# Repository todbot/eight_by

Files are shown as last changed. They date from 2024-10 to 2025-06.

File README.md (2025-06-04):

# eight_by

An 8-knob + 8 buttons + eight RGB LEDs board,<br/>
all controllable with only 8 pins

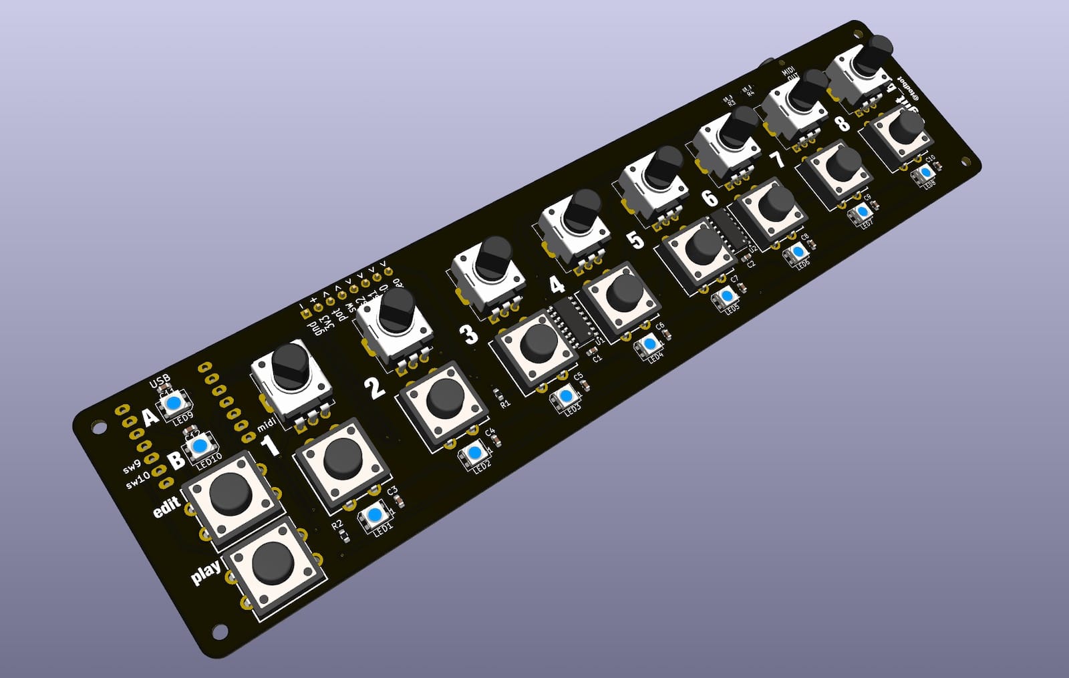
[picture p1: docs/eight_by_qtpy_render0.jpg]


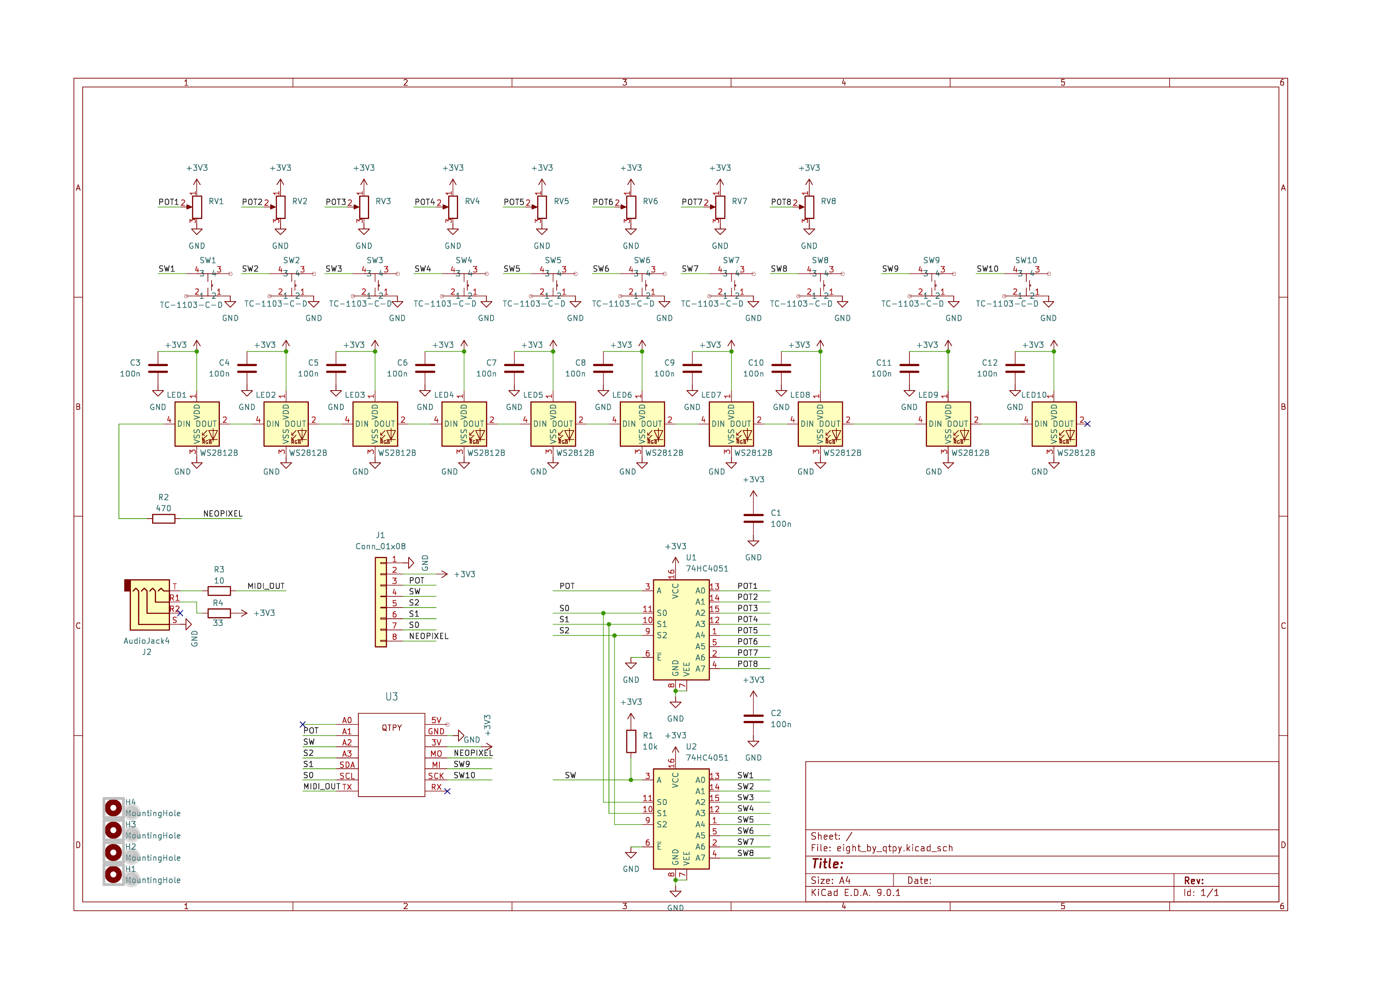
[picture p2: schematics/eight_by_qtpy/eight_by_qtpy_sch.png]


Pot options:

- 9mm Song Hui trimmer pots B10K - [synthcube](https://synthcube.com/cart/parts/potentiometers-and-trimpots/song-huei-9mm-panel-trim-pot-short)
- Just about any other 9mm pot

Buttons are: 
- 12mm tact (LCSC C561260)

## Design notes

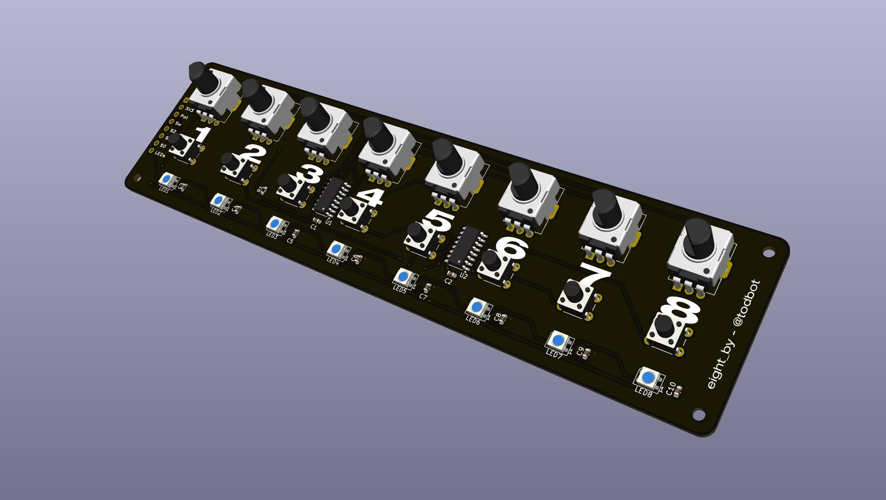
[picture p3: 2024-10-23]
docs/eight_by_render0.jpg

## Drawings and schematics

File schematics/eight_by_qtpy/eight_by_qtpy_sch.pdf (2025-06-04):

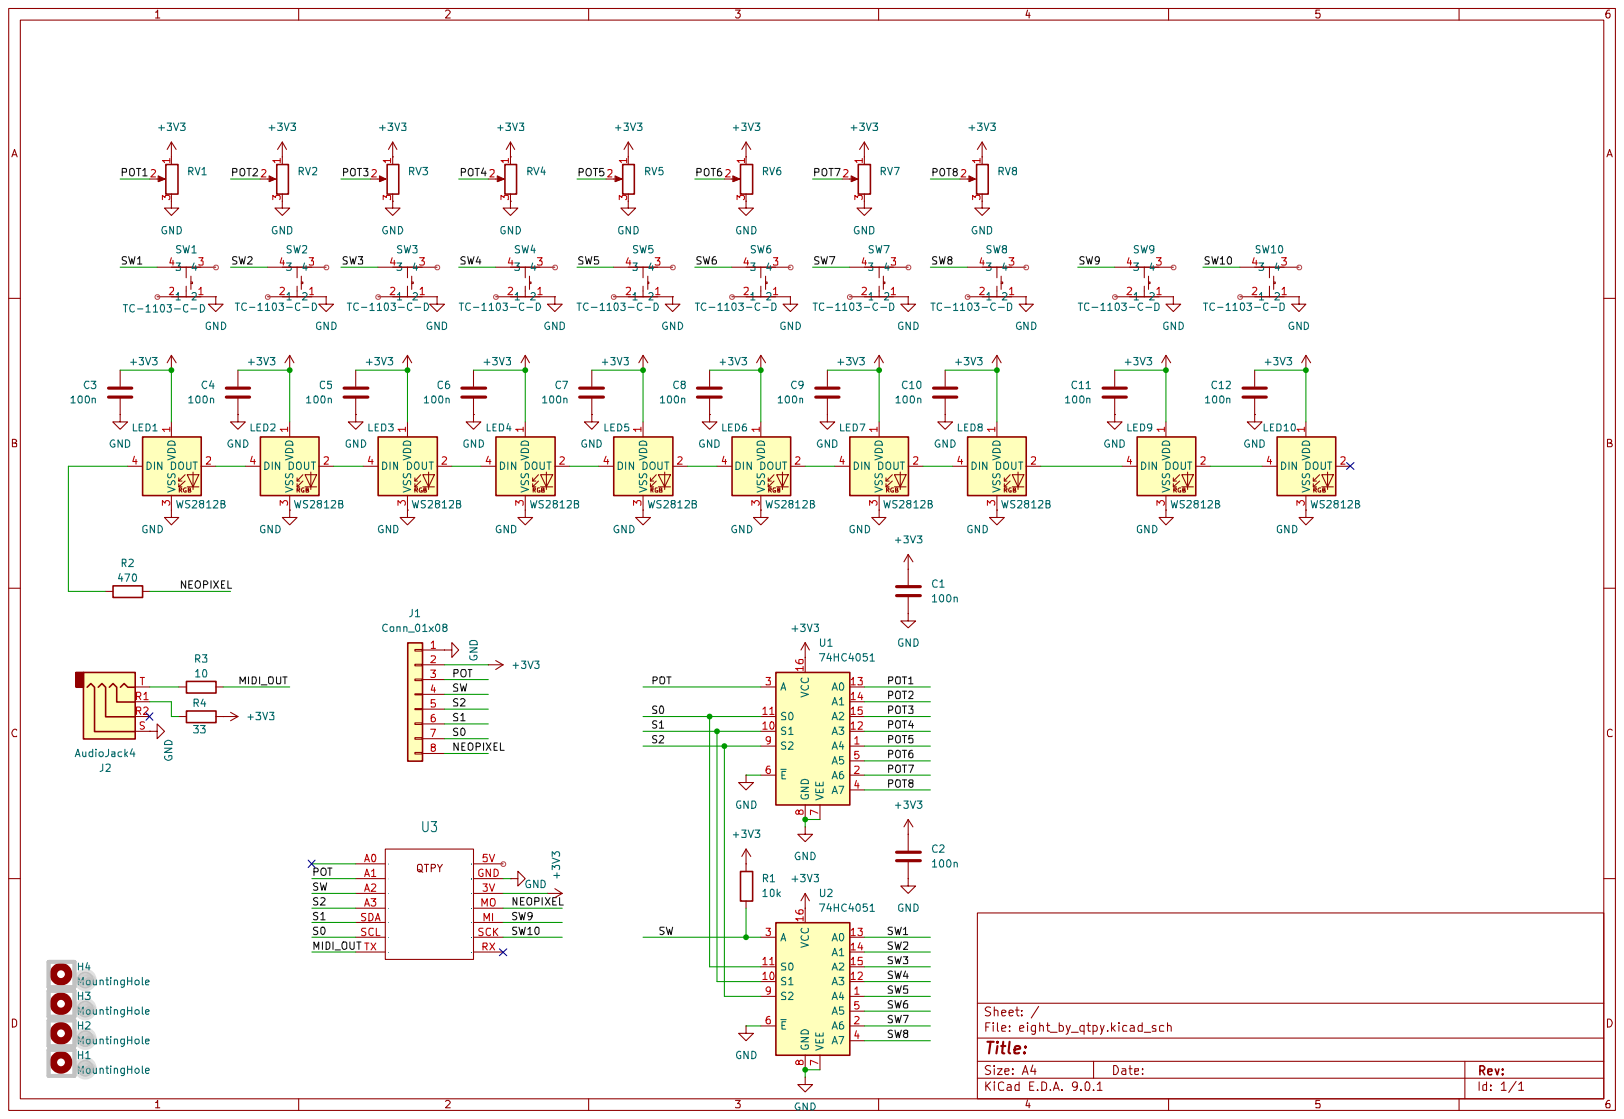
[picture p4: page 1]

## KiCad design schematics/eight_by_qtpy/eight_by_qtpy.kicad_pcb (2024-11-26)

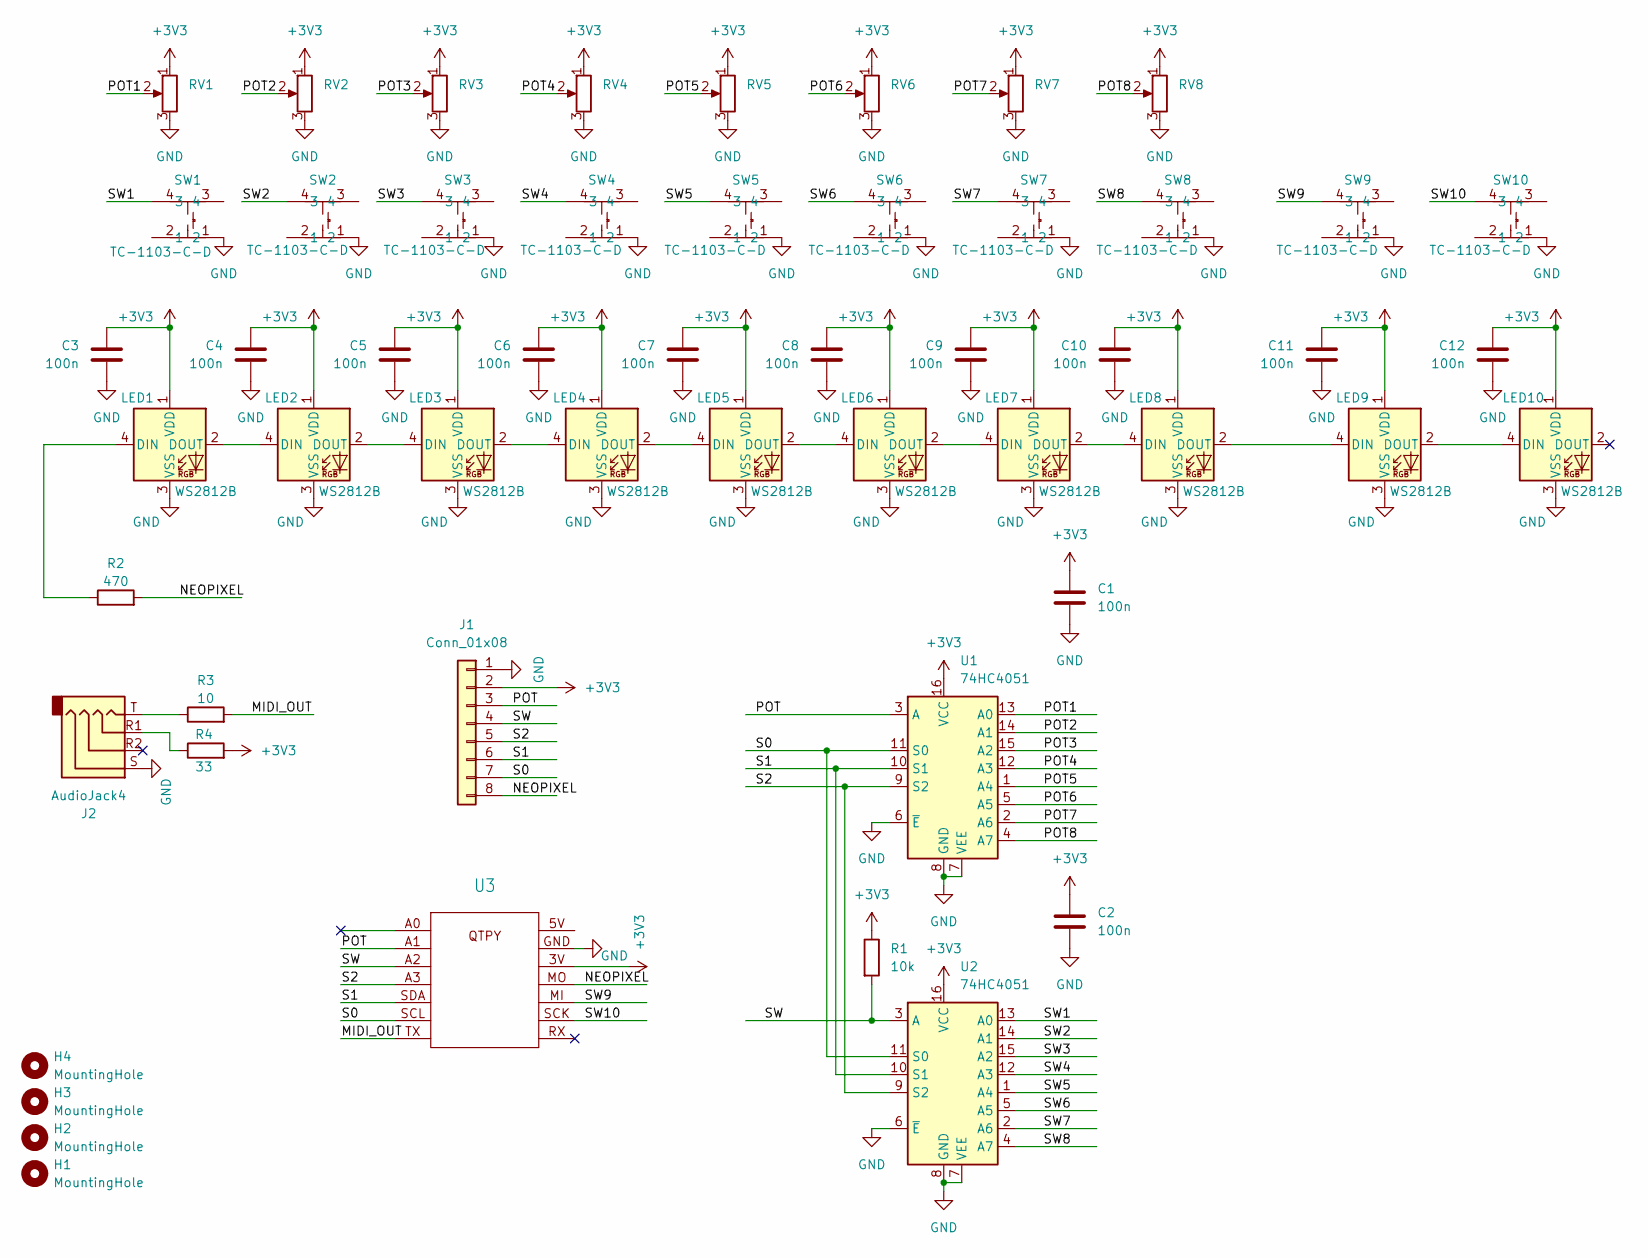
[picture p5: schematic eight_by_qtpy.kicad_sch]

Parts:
C1, C2, C3, C4, C5, C6, C7, C8, C9, C10, C11, C12: 100n; C_0603_1608Metric
H1, H2, H3, H4: MountingHole; MountingHole_2.5mm
J1: Conn_01x08; PinHeader_1x08_P2.54mm_Vertical
J2: AudioJack4; Jack_3.5mm_PJ320D_Horizontal
LED1, LED2, LED3, LED4, LED5, LED6, LED7, LED8, LED9, LED10: WS2812B; LED_WS2812B-Mini_PLCC4_3.5x3.5mm
R1: 10k; R_0603_1608Metric
R2: 470; R_0603_1608Metric
R3: 10; R_0603_1608Metric
R4: 33; R_0603_1608Metric
RV1, RV2, RV3, RV4, RV5, RV6, RV7, RV8: R_Potentiometer; Potentiometer_Alps_RK09K_Single_Vertical
SW1, SW2, SW3, SW4, SW5, SW6, SW7, SW8, SW9, SW10: TC-1103-C-D; SW-TH_4P-L12.0-W12.0-P5.00-LS12.5; LCSC Part C561260
U1, U2: 74HC4051; SOIC-16_3.9x9.9mm_P1.27mm
U3: QTPY_TH_HEADERSOCKET

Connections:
+3V3: C1.1, C2.1, C3.1, C4.1, C5.1, C6.1, C7.1, C8.1, C9.1, C10.1, C11.1, C12.1, J1.2, LED1.1 (VDD), LED2.1 (VDD), LED3.1 (VDD), LED4.1 (VDD), LED5.1 (VDD), LED6.1 (VDD), LED7.1 (VDD), LED8.1 (VDD), LED9.1 (VDD), LED10.1 (VDD), R1.1, R4.2, RV1.1, RV2.1, RV3.1, RV4.1, RV5.1, RV6.1, RV7.1, RV8.1, U1.16 (VCC), U2.16 (VCC), U3.3V
/MIDI_OUT: R3.2, U3.TX
/NEOPIXEL: J1.8, R2.2, U3.MO
/POT: J1.3, U1.3 (A), U3.A1 (9)
/POT1: RV1.2, U1.13 (A0)
/POT2: RV2.2, U1.14 (A1)
/POT3: RV3.2, U1.15 (A2)
/POT4: RV4.2, U1.12 (A3)
/POT5: RV5.2, U1.1 (A4)
/POT6: RV6.2, U1.5 (A5)
/POT7: RV7.2, U1.2 (A6)
/POT8: RV8.2, U1.4 (A7)
/S0: J1.7, U1.11 (S0), U2.11 (S0), U3.SCL
/S1: J1.6, U1.10 (S1), U2.10 (S1), U3.SDA
/S2: J1.5, U1.9 (S2), U2.9 (S2), U3.A3
/SW: J1.4, R1.2, U2.3 (A), U3.A2
/SW1: SW1.4, U2.13 (A0)
/SW2: SW2.4, U2.14 (A1)
/SW3: SW3.4, U2.15 (A2)
/SW4: SW4.4, U2.12 (A3)
/SW5: SW5.4, U2.1 (A4)
/SW6: SW6.4, U2.5 (A5)
/SW7: SW7.4, U2.2 (A6)
/SW8: SW8.4, U2.4 (A7)
/SW9: SW9.4, U3.MI
/SW10: SW10.4, U3.SCK
GND: C1.2, C2.2, C3.2, C4.2, C5.2, C6.2, C7.2, C8.2, C9.2, C10.2, C11.2, C12.2, J1.1, J2.S, LED1.3 (VSS), LED2.3 (VSS), LED3.3 (VSS), LED4.3 (VSS), LED5.3 (VSS), LED6.3 (VSS), LED7.3 (VSS), LED8.3 (VSS), LED9.3 (VSS), LED10.3 (VSS), RV1.3, RV2.3, RV3.3, RV4.3, RV5.3, RV6.3, RV7.3, RV8.3, SW1.1, SW2.1, SW3.1, SW4.1, SW5.1, SW6.1, SW7.1, SW8.1, SW9.1, SW10.1, U1.6 (~E), U1.7 (VEE), U1.8 (GND), U2.6 (~E), U2.7 (VEE), U2.8 (GND), U3.GND (14)
unnamed: J2.R1, R4.1
unnamed: J2.T, R3.1
unnamed: LED1.4 (DIN), R2.1
unnamed: LED1.2 (DOUT), LED2.4 (DIN)
unnamed: LED2.2 (DOUT), LED3.4 (DIN)
unnamed: LED3.2 (DOUT), LED4.4 (DIN)
unnamed: LED4.2 (DOUT), LED5.4 (DIN)
unnamed: LED5.2 (DOUT), LED6.4 (DIN)
unnamed: LED6.2 (DOUT), LED7.4 (DIN)
unnamed: LED7.2 (DOUT), LED8.4 (DIN)
unnamed: LED8.2 (DOUT), LED9.4 (DIN)
unnamed: LED9.2 (DOUT), LED10.4 (DIN)

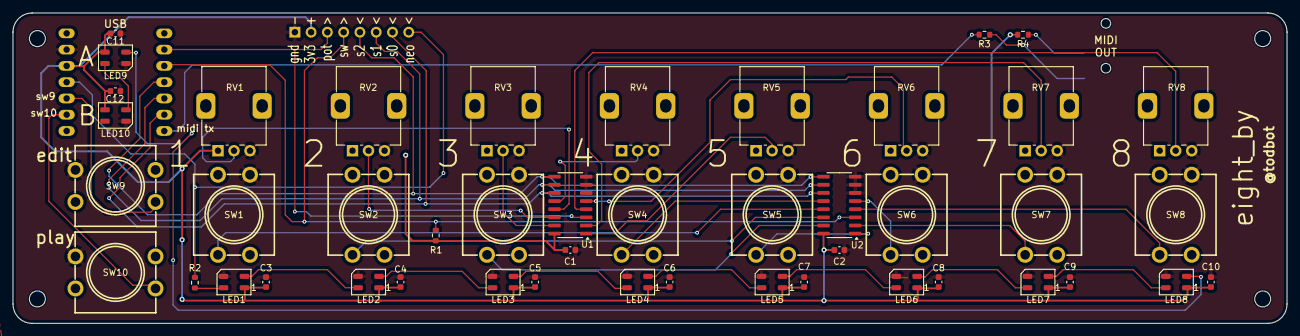
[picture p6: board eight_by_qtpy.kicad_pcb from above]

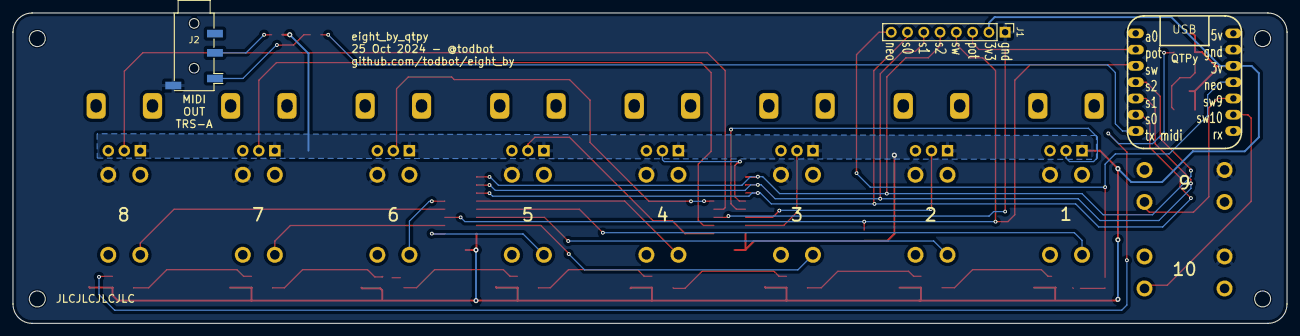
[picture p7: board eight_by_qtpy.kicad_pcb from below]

Board: 2 copper layers, 198.9 x 48.4 mm, 53 parts (3 on the bottom side), 39 nets.

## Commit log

2024-06-27 pcb silkscren update
    [eight_by.kicad_pcb]
2024-10-24 eight_by_qtpy idea
    [eight_by.kicad_pcb, eight_by_qtpy.kicad_pcb, eight_by_qtpy.kicad_sch]
2024-10-24 add two extra buttons & LEDs if using a QTpy
    [eight_by_qtpy.kicad_pcb, eight_by_qtpy.kicad_sch]
2024-10-26 clean up
    [eight_by_qtpy.kicad_pcb]
2024-11-14 rethinking eight_by_qtpy
    [eight_by_qtpy.kicad_pcb]
2024-11-23 new silkscreen
    [eight_by_qtpy.kicad_pcb]
2024-11-24 refactor eight_by_qtpy to use 12mm switches instead of std 6mm tact
    [eight_by_qtpy.kicad_pcb, eight_by_qtpy.kicad_sch]
2024-11-25 clea up eight_by_qtpy refactor layout
    [eight_by_qtpy.kicad_pcb]
2024-11-25 clean up eight_by_qtpy refactor layout
    [eight_by_qtpy.kicad_pcb]
2024-11-26 files as sent to fab
    [eight_by_qtpy.kicad_pcb]
